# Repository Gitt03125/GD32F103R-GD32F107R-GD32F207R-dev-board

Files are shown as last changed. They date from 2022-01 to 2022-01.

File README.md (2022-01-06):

# GD32F103R GD32F107R GD32F207R development board

This board can be used with the `GD32F103Rx` and the `GD32F107Rx` , `GD32F207Rx` (Ethernet) MCU's. 

Please note that the crystal for the `GD32F107Rx` and the `GD32F207Rx` is `25MHz` and the crystal for the `GD32F103Rx` is `8MHz`.

The USB is power and DFU.

The 2x13 header is pin compatible with the Orange Pi Zero and Raspberry Pi boards. 

<table style="width:100%">
	<tr><th colspan="8">2x13 Header</th>
	</tr>
	<tr>
	<td></td>
	<td colspan="2" style="background-color:#FFA500">3.3V PWR</td>
	<td>1</td>
	<td>2</td>
	<td colspan="2" style="background-color:#FF0000">5V PWR</td>
	<td rowspan="2"></td>
	</tr>
	<tr>
	<td rowspan="2">REMAP = 0</td>
	<td style="background-color:#EE82EE">I2C0 SCA</td>
	<td>PB7</td>
	<td>3</td>
	<td>4</td>
	<td colspan="2" style="background-color:#FF0000">5V PWR</td>
	</tr>
	<tr>
	<td style="background-color:#EE82EE">I2C0 SCL</td>
	<td>PB6</td>
	<td>5</td>
	<td>6</td>
	<td colspan="2">GND</td>
	<td></td>
	</tr>
	<tr>
	<td colspan="2"></td>
	<td>PA6</td>
	<td>7</td>
	<td>8</td>
	<td>PC10</td>
	<td style="background-color:#4169E1">USART2 TX</td>
	<td rowspan="2">REMAP [1:0] =“01” (partial remap)</td>
	</tr>
	<tr>
	<td></td>
	<td colspan="2">GND</td>
	<td>9</td>
	<td>10</td>
	<td>PC11</td>
	<td style="background-color:#4169E1">USART2 RX</td>
	</tr>
	<tr>
	<td rowspan="2">REMAP = 0</td>
	<td style="background-color:#4169E1">USART5 RX</td>
	<td>PC7</td>
	<td>11</td>
	<td>12</td>
	<td>PB10</td>
	<td colspan="2"></td>
	</tr>
	<tr>
	<td style="background-color:#4169E1">USART5 TX</td>
	<td>PC6</td>
	<td>13</td>
	<td>14</td>
	<td colspan="2">GND</td>
	<td></td>
	</tr>
	<tr>
	<td colspan="2"></td>
	<td>PB14</td>
	<td>15</td>
	<td>16</td>
	<td>PB15</td>
	<td colspan="2"></td>
	</tr>
	<tr>
	<td></td>
	<td colspan="2" style="background-color:#FFA500">3.3V PWR</td>
	<td>17</td>
	<td>18</td>
	<td>PA13</td>
	<td style="background-color:#F0FFFF">SWDIO</td>
	<td></td>
	</tr>
	<tr>
	<td></td>
	<td style="background-color:#00F000">SPI2 MOSI</td>
	<td>PB5</td>
	<td>19</td>
	<td>20</td>
	<td colspan="2">GND</td>
	<td></td>
	</tr>
	<tr>
	<td></td>
	<td style="background-color:#00F000">SPI2 MISO</td>
	<td>PB4</td>
	<td>21</td>
	<td>22</td>
	<td>PA11</td>
	<td colspan="2"></td>
	</tr>
	<tr>
	<td></td>
	<td style="background-color:#00F000">SPI2 SCK</td>
	<td>PB3</td>
	<td>23</td>
	<td>24</td>
	<td>PA15</td>
	<td style="background-color:#00F000">SPI2 CS</td>
	<td></td>
	</tr>
	<tr>
	<td></td>
	<td colspan="2">GND</td>
	<td>25</td>
	<td>26</td>
	<td>PA14</td>
	<td style="background-color:#F0FFFF">SWCLK</td>
	<td></td>
	</tr>
</table>

<table>
	<tr><th colspan="4">1x13 Header</th></tr>
	<tr>
	<td>1</td>
	<td colspan="2">NC</td>
	</tr>
	<tr>
	<td>2</td>
	<td colspan="2">GND</td>
	</tr>
	<tr>
	<td>3</td>
	<td>PA14</td>
	<td style="background-color:#F0FFFF">SWCLK</td>
	</tr>
	<tr>
	<td>4</td>
	<td colspan="2">GND</td>
	</tr>
	<tr>
	<td>5</td>
	<td>PA13</td>
	<td style="background-color:#F0FFFF">SWDIO</td>
	</tr>
	<tr>
	<td>6</td>
	<td colspan="2">NRST</td>
	</tr>
	<tr>
	<td>7</td>
	<td>PA5</td>
	<td style="background-color:#FFFFEF">DAC1</td>
	</tr>
	<tr>
	<td>8</td>
	<td>PA4</td>
	<td style="background-color:#FFFFEF">DAC0</td>
	</tr>
	<tr>
	<td>9</td>
	<td>PC12</td>
	<td style="background-color:#4169E1">UART4 TX</td>
	</tr>
	<tr>
	<td>10</td>
	<td>PD2</td>
	<td style="background-color:#4169E1">UART4 RX</td>
	</tr>
	<tr>
	<td>11</td>
	<td>PB6</td>
	<td style="background-color:#4169E1">USART0 TX</td>
	<td rowspan="2">REMAP = 1</td>
	</tr>
	<tr>
	<td>12</td>
	<td>PB7</td>
	<td style="background-color:#4169E1">USART0 RX</td>
	</tr>
	<tr>
	<td>13</td>
	<td colspan="2">GND</td>
	</tr>
</table>

<table>
	<tr><th colspan="2">Boot UART</th></tr>
	<tr>
	<td>1</td>
	<td>GND</td>
	</tr>
	<tr>
	<td>2</td>
	<td style="background-color:#4169E1"> USART0 RX</td>
	<td>PA10</td>
	<td rowspan="2">REMAP = 0</td>
	</tr>
	<tr>
	<td>3</td>
	<td style="background-color:#4169E1"> USART0 TX</td>
	<td>PA9</td>
	</tr>	
</table>

<table>
<head>
	<tr>
	<th colspan="2">LED's</th>
	</tr>
</head>
<tbody>
	<tr>
	<td>1</td>
	<td>PC0</td>
	</tr>
	<tr>
	<td>2</td>
	<td>PC2</td>
	</tr>
	<tr>
	<td>3</td>
	<td>PC3</td>
	</tr>
	<tr>
	<td>4</td>
	<td>3V3</td>
	</tr>	
</tbody>
</table>

<table>
	<tr><th colspan="4">2x7 Header</th></tr>
	<tr>
	<td>PB13</td>
	<td>1</td>
	<td>2</td>
	<td>NC</td>
	</tr>
	<tr>
	<td>PB11</td>
	<td>3</td>
	<td>4</td>
	<td>PB12</td>
	</tr>
	<tr>
	<td>PC4</td>
	<td>5</td>
	<td>6</td>
	<td>PC5</td>
	</tr>
	<tr>
	<td>PA1</td>
	<td>7</td>
	<td>8</td>
	<td>PA7</td>
	</tr>
	<tr>
	<td>PA2</td>
	<td>9</td>
	<td>10</td>
	<td>PC1</td>
	</tr>
	<tr>
	<td>GND</td>
	<td>11</td>
	<td>12</td>
	<td>GND</td>
	</tr>
	<tr>
	<td style="background-color:#FFA500">3V3</td>
	<td>13</td>
	<td>14</td>
	<td style="background-color:#FFA500">3V3</td>
	</tr>	
</table>

### GD32F103Rx (only)

<table>
<head>
<tr><th colspan="5">1x4 Header</th></tr>
</head>
<tbody>
<tr>
<td></td>
<td>GND</td>
<td>1</td>
<td>GND</td>
<td></td>
</tr>
<tr>
<td></td>
<td style="background-color:#FFA500">3V3</td>
<td>2</td>
<td style="background-color:#FFA500">3V3</td>
<td></td>
</tr>
<tr>
<td rowspan="2">REMAP[1:0] = 00/01</td>
<td style="background-color:#EE82EE">I2C1 SCL</td>
<td>3</td>
<td style="background-color:#4169E1">USART2 RX</td>
<td rowspan="2">REMAP = 0 (no remap)</td>
</tr>
<tr>
<td style="background-color:#EE82EE">I2C1 SCA</td>
<td>4</td>
<td style="background-color:#4169E1">USART2 TX</td>
</tr>	
</tbody>
</table>

### GD32F107Rx GD32F207Rx (only)

<table>
<head>
<tr>
<th colspan="4">External-PHY</th>
</tr>
</head>
<tbody>
<tr>
<td>RMII TXD1</td>
<td>1</td>
<td>2</td>
<td>NC</td>
</tr>
<tr>
<td>RMII TX_EN</td>
<td>3</td>
<td>4</td>
<td>RMII TXD0</td>
</tr>
<tr>
<td>RMII RXD0</td>
<td>5</td>
<td>6</td>
<td>RMII RXD1</td>
</tr>
<tr>
<td>RMII REF_CLK</td>
<td>7</td>
<td>8</td>
<td>RMII CRS_DV</td>
</tr>
<tr>
<td>MDIO</td>
<td>9</td>
<td>10</td>
<td>MDC</td>
</tr>
<tr>
<td>GND</td>
<td>11</td>
<td>12</td>
<td>GND</td>
</tr>
<tr>
<td style="background-color:#FFA500">3V3</td>
<td>13</td>
<td>14</td>
<td style="background-color:#FFA500">3V3</td>
</tr>		
</tbody>
</table>

[PayPal.Me Donate](https://paypal.me/AvanVught?locale.x=nl_NL)

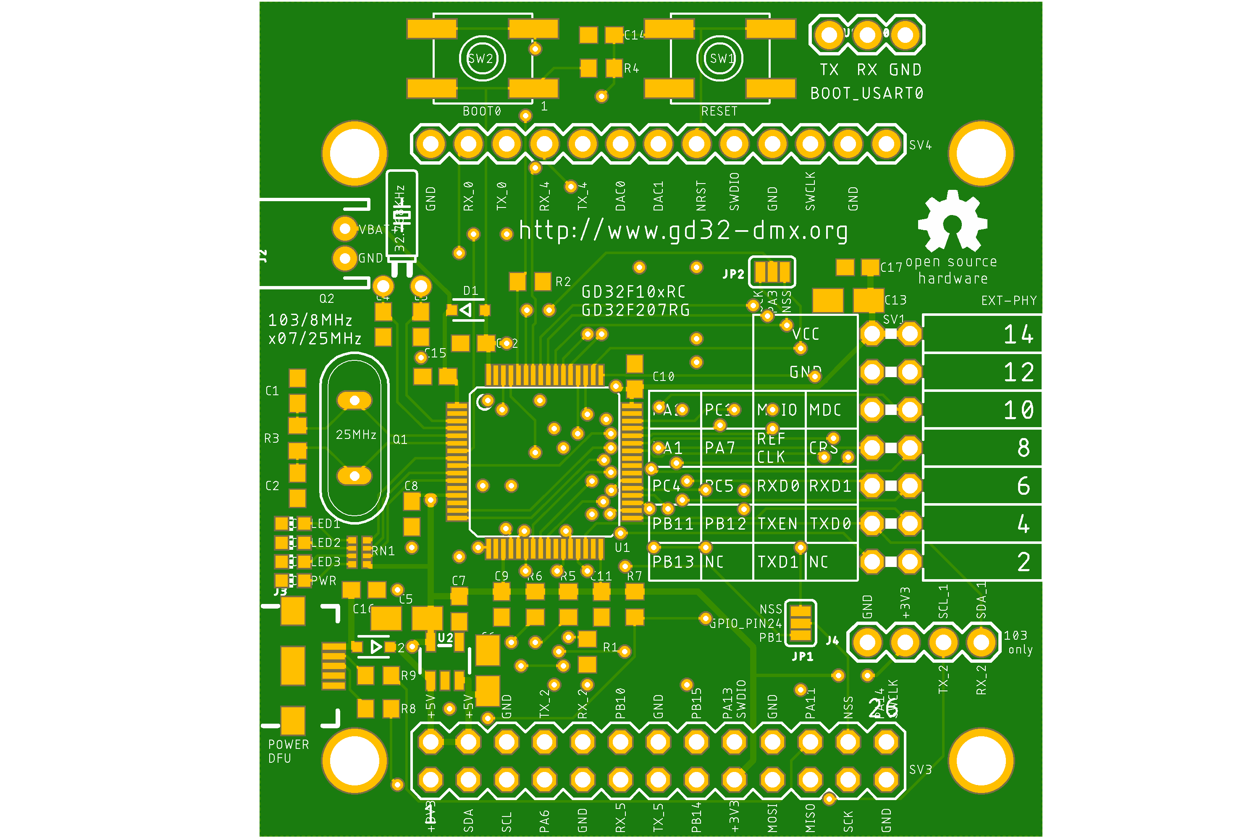
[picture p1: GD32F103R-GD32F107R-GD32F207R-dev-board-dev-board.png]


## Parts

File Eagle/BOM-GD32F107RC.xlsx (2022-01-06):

Qty | Designator | Footprint | Comment | LCSC Part #
2 | C1, C2 | C0603 | 20pF | C1648
2 | C3, C4 | C0603 | 10pF | C1634
3 | C5, C6, C13 | A/3216-18R | 10uF | C7171
10 | C7, C8, C9, C10, C11, C12, C14, C15, C16, C17 | C0603 | 100n | C14663
4 | LED1, LED2, LED3, LED4 | CHIP-LED0603 | LEDCHIP-LED0603 | C72043
2 | D1, D2 | SOD323-R | 1N5819 | C191023
3 | R1, R2, R4 | R0603 | 10K | C25804
1 | R3 | R0603 | 1M | C22935
2 | R5,R6 | R0603 | 4K7 | C23162
1 | R7 | R0603 | 1K5 | C4190
2 | R8, R9 | R0603 | 22R | C23345
1 | RN1 | 4X0402ARV341 | 2K | C44891
1 | U1 | LQFP64 | GD32F107 | C94285
1 | U2 | SOT23-5 | TPRT9013-33GB | C587158
1 | J3 | USB_MICRO-B_FEMALE-SMT | USB-B-MICRO-SMD | C404968
2 | SW1, SW2 | EVQ-Q2 | SPST 6*6mm Tactile Switch | C221880
36

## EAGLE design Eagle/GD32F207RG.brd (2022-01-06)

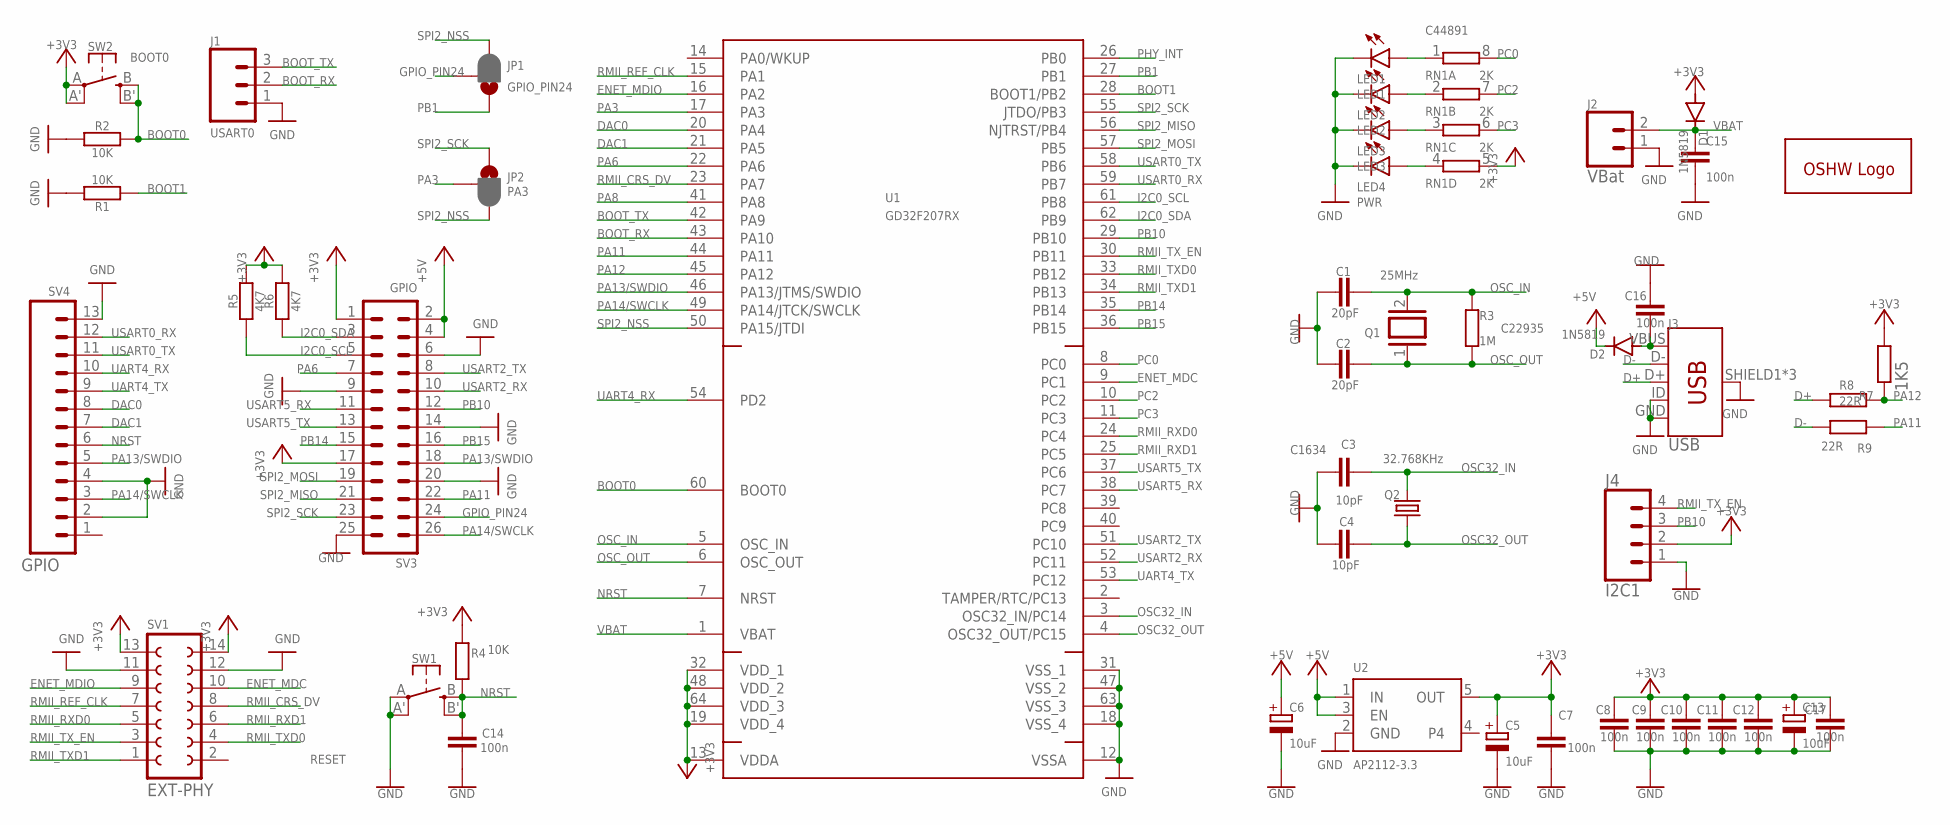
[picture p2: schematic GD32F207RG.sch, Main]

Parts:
C1, C2: 20pF; C0603; JLCPCB C1648
C3, C4: 10pF; C0603; JLCPCB C1634
C5, C6, C13: 10uF; A/3216-18R; JLCPCB C7171
C7, C8, C9, C10, C11, C12, C14, C15, C16, C17: 100n; C0603; JLCPCB C14663
D1, D2: 1N5819; SOD323-R; JLCPCB C191023
GOLD_ORB_SM1: OSHWLOGOLOGO5MM; OSHW_5MM
J1: USART0; 1X03
J2: VBat; JST-2-PTH
J3: USB; USB-B-MICRO-SMD; JLCPCB C404968
J4: I2C1; 1X04
JP1: GPIO_PIN24; SMT-JUMPER_3_1-NC_PASTE_SILK
JP2: PA3; SMT-JUMPER_3_1-NC_PASTE_SILK
LED1: LED1; CHIP-LED0603
LED2: LED2; CHIP-LED0603
LED3: LED3; CHIP-LED0603
LED4: PWR; CHIP-LED0603
Q1: 25MHz; QS
Q2: 32.768KHz; TC26H
R1, R2, R4: 10K; R0603; JLCPCB C25804
R3: 1M; R0603; JLCPCB C22935
R5, R6: 4K7; R0603; JLCPCB C23162
R7: 1K5; R0603; JLCPCB C4190
R8, R9: 22R; R0603; JLCPCB C23345
RN1: 2K; 4X0402ARV341; JLCPCB C44891
SV1: EXT-PHY; FE07-2W
SV3: GPIO; MA13-2
SV4: GPIO; 1X13
SW1: RESET; EVQ-Q2
SW2: BOOT0; EVQ-Q2; JLCPCB C221880
U1: GD32F207RX; LQFP64
U2: AP2112-3.3; SOT23-5; JLCPCB C51118

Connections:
+3V3: C5.+, C7.1, C8.1, C9.1, C10.1, C11.1, C12.1, C13.+, C17.1, D1.A, J4.2, R4.2, R5.2, R6.2, R7.2, RN1.5 (2), SV1.13, SV1.14, SV3.1, SV3.17, SW2.A, SW2.A' (P1), U1.13 (VDDA), U1.19 (VDD_4), U1.32 (VDD_1), U1.48 (VDD_2), U1.64 (VDD_3), U2.5 (OUT)
+5V: C6.+, D2.C, SV3.2, SV3.4, U2.1 (IN), U2.3 (EN)
BOOT0: R2.2, SW2.B (S), SW2.B' (S1), U1.60 (BOOT0)
BOOT1: R1.1, U1.28 (BOOT1/PB2)
BOOT_RX: J1.2, U1.43 (PA10)
BOOT_TX: J1.3, U1.42 (PA9)
D+: J3.D+, R8.1
D-: J3.D-, R9.1
DAC0: SV4.8, U1.20 (PA4)
DAC1: SV4.7, U1.21 (PA5)
ENET_MDC: SV1.10, U1.9 (PC1)
ENET_MDIO: SV1.9, U1.16 (PA2)
GND: C1.1, C2.1, C3.1, C4.1, C5.-, C6.-, C7.2, C8.2, C9.2, C10.2, C11.2, C12.2, C13.-, C14.2, C15.2, C16.1, C17.2, J1.1, J2.1, J3.GND, J3.ID, J3.SHIELD1 (SHIELD), J3.SHIELD2 (SHIELD), J3.SHIELD3 (SHIELD), J4.1, LED1.C, LED2.C, LED3.C, LED4.C, R1.2, R2.1, SV1.11, SV1.12, SV3.6, SV3.9, SV3.14, SV3.20, SV3.25, SV4.2, SV4.4, SV4.13, SW1.A, SW1.A' (P1), U1.12 (VSSA), U1.18 (VSS_4), U1.31 (VSS_1), U1.47 (VSS_2), U1.63 (VSS_3), U2.2 (GND)
GPIO_PIN24: JP1.2, SV3.24
I2C0_SCL: R5.1, SV3.5, U1.61 (PB8)
I2C0_SDA: R6.1, SV3.3, U1.62 (PB9)
unnamed: LED1.A, RN1.1
unnamed: LED2.A, RN1.2 (1)
unnamed: LED3.A, RN1.3 (1)
unnamed: LED4.A, RN1.4 (1)
NRST: C14.1, R4.1, SV4.6, SW1.B (S), SW1.B' (S1), U1.7 (NRST)
OSC32_IN: C3.2, Q2.2, U1.3 (OSC32_IN/PC14)
OSC32_OUT: C4.2, Q2.1, U1.4 (OSC32_OUT/PC15)
OSC_IN: C1.2, Q1.2, R3.2, U1.5 (OSC_IN)
OSC_OUT: C2.2, Q1.1, R3.1, U1.6 (OSC_OUT)
PA3: JP2.2, U1.17 (PA3)
PA6: SV3.7, U1.22 (PA6)
PA8: U1.41 (PA8)
PA11: R9.2, SV3.22, U1.44 (PA11)
PA12: R7.1, R8.2, U1.45 (PA12)
PA13/SWDIO: SV3.18, SV4.5, U1.46 (PA13/JTMS/SWDIO)
PA14/SWCLK: SV3.26, SV4.3, U1.49 (PA14/JTCK/SWCLK)
PB1: JP1.1, U1.27 (PB1)
PB10: J4.3, SV3.12, U1.29 (PB10)
PB14: SV3.15, U1.35 (PB14)
PB15: SV3.16, U1.36 (PB15)
PC0: RN1.8 (2), U1.8 (PC0)
PC2: RN1.7 (2), U1.10 (PC2)
PC3: RN1.6 (2), U1.11 (PC3)
PHY_INT: U1.26 (PB0)
RMII_CRS_DV: SV1.8, U1.23 (PA7)
RMII_REF_CLK: SV1.7, U1.15 (PA1)
RMII_RXD0: SV1.5, U1.24 (PC4)
RMII_RXD1: SV1.6, U1.25 (PC5)
RMII_TXD0: SV1.4, U1.33 (PB12)
RMII_TXD1: SV1.1, U1.34 (PB13)
RMII_TX_EN: J4.4, SV1.3, U1.30 (PB11)
SPI2_MISO: SV3.21, U1.56 (NJTRST/PB4)
SPI2_MOSI: SV3.19, U1.57 (PB5)
SPI2_NSS: JP1.3, JP2.3, U1.50 (PA15/JTDI)
SPI2_SCK: JP2.1, SV3.23, U1.55 (JTDO/PB3)
UART4_RX: SV4.10, U1.54 (PD2)
UART4_TX: SV4.9, U1.53 (PC12)
USART0_RX: SV4.12, U1.59 (PB7)
USART0_TX: SV4.11, U1.58 (PB6)
USART2_RX: SV3.10, U1.52 (PC11)
USART2_TX: SV3.8, U1.51 (PC10)
USART5_RX: SV3.11, U1.38 (PC7)
USART5_TX: SV3.13, U1.37 (PC6)
VBAT: C15.1, D1.C, J2.2, U1.1 (VBAT)
VBUS: C16.2, D2.A, J3.VBUS

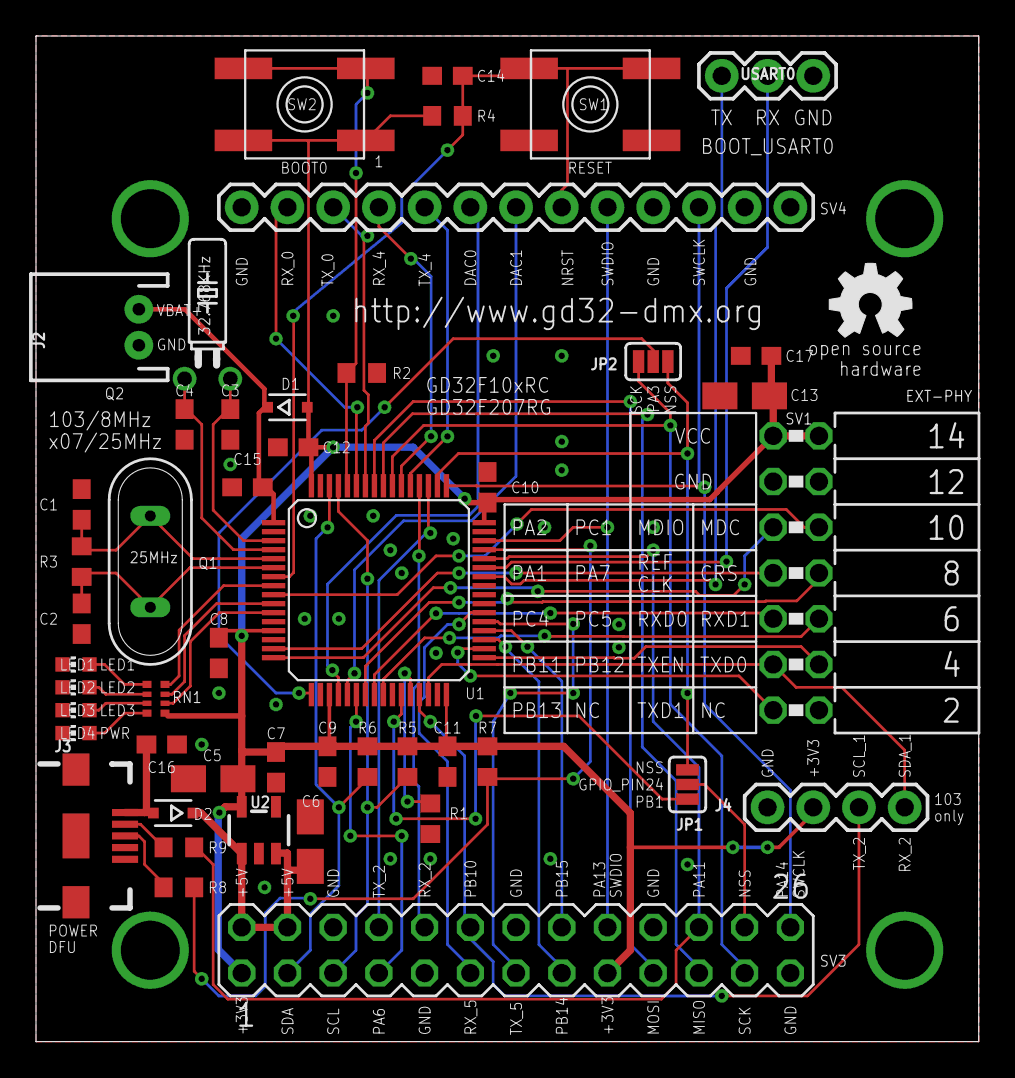
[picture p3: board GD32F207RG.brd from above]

Board: 2 copper layers, 52.4 x 55.9 mm, 49 parts (0 on the bottom side), 59 nets.

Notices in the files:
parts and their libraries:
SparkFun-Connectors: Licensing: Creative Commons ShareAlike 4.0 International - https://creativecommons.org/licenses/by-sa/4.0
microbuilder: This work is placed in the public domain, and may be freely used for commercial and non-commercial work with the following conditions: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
